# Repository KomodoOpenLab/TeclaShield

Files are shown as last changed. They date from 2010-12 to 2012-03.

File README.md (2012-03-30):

Tecla Shield
============

The [Tecla Shield](http://mobile-accessibility.idrc.ocad.ca/projects/tekla/the-shield) is a device that enables connection of powered wheelchairs and adapted switches to Bluetooth-enabled electronic devices. Together with the [Tecla App](http://komodoopenlab.com/tecla/the-app/), the Tecla Shield may be used to access and control Android-powered devices and is also available for the iPhone and iPad.

Getting Involved
----------------
There are many ways to contribute to the development of the Tecla Shield. Here are some ideas:

### Code

In order to start contributing code and/or designs to the Tecla Shield project, follow the steps below:

1. Fork this repo. For detailed instructions visit [http://help.github.com/fork-a-repo/](http://help.github.com/fork-a-repo/)
2. To work on the firmware, download and install the [Arduino software](http://arduino.cc/en/Main/Software)
3. The firmware for the Tecla Shield is available in the *sketches* directory, simply open the project you want to work on from the Arduino development environment.
4. Hack away! but please make sure you follow [this branching model] (http://nvie.com/posts/a-successful-git-branching-model/). That means, make your pull requests against the **develop** branch, not the **master** branch.

### Review

Another very useful way to contribute to the Tecla Shield project is to identify any bugs or issues that may still be lurking around. You can also submit requests for the features that you think the Tecla Shield is still missing. To get started, follow the steps below:

1. [Sign up for a fee github account](https://github.com/signup/free) if you don't already have one
2. Report issues and submit feature requests to your heart's content via a the [Tecla Shield issues page](https://github.com/jorgesilva/TeclaShield/issues)

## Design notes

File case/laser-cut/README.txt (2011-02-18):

Case adapted from: Laser cut Ethernet shield / Arduino enclosure
URL: http://www.thingiverse.com/thing:5044
Original author: teabot (http://www.thingiverse.com/teabot)
Modified for Tekla on February 13, 2011 by Jorge Silva
Copyright (c) 2011, Inclusive Design Research Centre

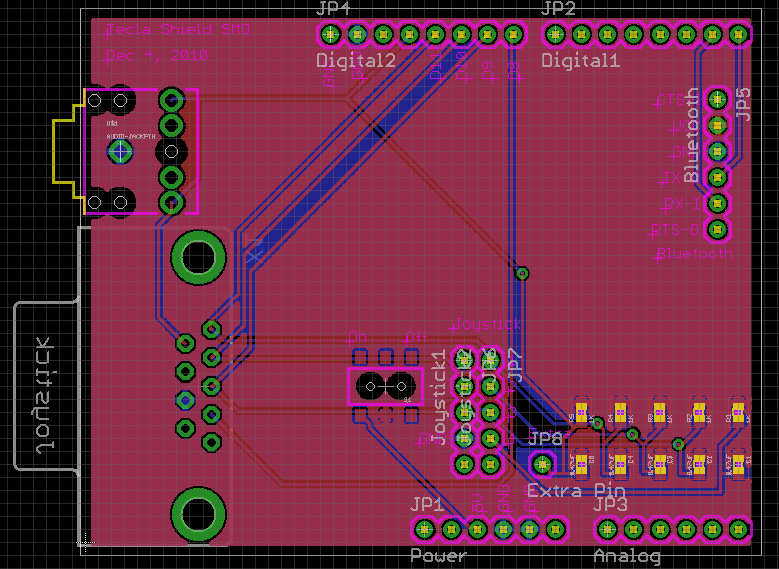
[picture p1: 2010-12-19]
board/SMD/TeklaShieldSMD.PNG

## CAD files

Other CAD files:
case/3d-model/case-bottom.skp
case/3d-model/case-everything.skp
case/3d-model/case-top.skp

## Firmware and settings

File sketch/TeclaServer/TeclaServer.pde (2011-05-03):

/*
 created  27 Sep 2005
 modified 30 Dec 2009 by Tom Igoe
 	
 modified for Tekla
 25 May 2010 by Jorge Silva,
 3 June 2010 by Zongyi Yang
 3 May 2011 by Jorge Silva
 
 */

// Variables will change:
byte switchState = 0x3F;       // current switch states
byte extraState = 0x0C;        // extra switch state helper
byte prevSwitchState = 0x3F;   // previous switch states
byte mByte;                    // used to store incoming serial port data

void setup() {
  // initialize inputs without changing the direction of pins we don't care about
  // 0 = input, 1 = output
  DDRC &= 0xF0; // Joystick inputs
  DDRD &= 0xF3; // Extra inputs
  // initialize serial communication
  Serial.begin(115200);
}


void loop() {
  // if incoming byte
  if (Serial.available() > 0) {
    // get incoming byte:
    mByte = Serial.read();
    // echo incoming byte:
    Serial.write(mByte);
  } else {
    // read the switch states (6 switches):
    switchState = PINC & 0x0F;  // read joystick switches
    extraState = PIND & 0x0C;   // read extra switches
    extraState <<= 2;           // shift extra switches to most significant nibble
    switchState |= extraState;  // copy extra switches to switchState
    // compare the switchState to its previous state
    if (switchState != prevSwitchState) {
      // if the state has changed, send to serial port
      Serial.write(switchState);
      // save the current state as the last state for next time through the loop
      prevSwitchState = switchState;
    }
  }
}

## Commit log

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2010-05-25 Adding latest arduino code for server. Implements full bluetooth edge detection notification functionality.
2010-05-25 Had to create full_server folder and move the code into it for the arduino IDE to read it properly
2010-05-31 Added python testing server with no SDP/UUID support so Android client must connect via:
    Method m = dev.getClass().getMethod("createRfcommSocket", new Class[] { int.class });
    sock = (BluetoothSocket)m.invoke(dev, Integer.valueOf(1));
    instead of using a UUID through SDP as it is the case with the BlueSMiRF module.
2010-06-04 Moved sensors block to feed input method in architecture diagram for android client
2010-06-04 Added schemtatic, still unfinished. Only need to connect serial port to circuit
    [untitled.sch]
2010-06-05 Turned bluetooth connection code into a service providing switch event broadcasts to the OS.
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2010-06-28 Tried again. Apparently adding the folder doesn't add the contents inside
    [schematic.brd, schematic.sch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]
2010-07-12 Added V3 and V4 of sheild. They are through hole and smd respectively, and include the audio jack.
    [schematic.brd, schematic.sch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]
2010-08-06 + Input method is now forced open after first use. + Lots of refactoring in preparation for merge with switch event provider and packaging/release!
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2010-08-16 Cleaned up files
    [Tecla Shield Through Hole V1.brd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]
2010-08-18 + Added full android client project based on switch event provider + Service starts at boot
2010-08-18 + Merged input method code + Eliminated boot startup code for switch event provider + Fixes #620054
2010-08-18 Merged separate switch event intents into a single one by using the Extras bundle
2010-08-19 + Started refactoring to break up long methods. Lots of work needed. + IME is now responding to bluetooth events from external switches
2010-08-20 + Added helper placeholder class to break up IME code + Renamed SwitchEventProvider and InputMethod files + Added direct toch support + Found and fixed a few crashing bugs from refactoring + Function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
2010-08-23 Renamed Files and cleaned them up
    [Tecla Shield SMD.brd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]
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2010-08-30 Updated designs folder structure
    [Tecla Shield SMD.brd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]
2010-08-30 Renamed shield files from tecla to tekla and eliminated spaces in file names
    [TeklaShieldSMD.brd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]
2010-09-07 Included case designs in a google sketchup file under designs/case
    [case_everything.skp]
2010-09-07 Fixed small bug in the design
    [case_everything.skp]
2010-09-07 Separated the case into the top and bottom piece in separate files.
    [case_bottom.skp, case_top.skp]
2010-09-07 Deleted some extra lines in the bottom piece
    [case_bottom.skp, case_everything.skp]
2010-09-20 Last case did not fit arduino, made following changes:
    Made all holes wider
    One pin out of the 3 on the ardiuno was a little out of place, moved it to correct place
    Widened case
    Changed some sizes such that there is a 0.5mm gap between pieces that fit together.
    [case_bottom.skp, case_everything.skp, case_top.skp]
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2010-10-04 Modified sheild files to extend the inputs a bit further.
    Also cleaned up some files
    [TeklaShieldSMD.brd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]
2010-10-04 forgot to update the date, now fixed
    [TeklaShieldSMD.brd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]
2010-10-08 Minor changes to shield component names
    [TeklaShieldSMD.brd, TeklaShieldSMD.sch, TeklaShieldThroughHole.brd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]
2010-10-08 Removed shield CAM files
    [TeklaShieldSMD.GBL, TeklaShieldSMD.GBS, TeklaShieldSMD.GTL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]
2010-10-11 + Initial commit for Android 0.2-alpha + Removed all Android 0.1.X alpha code + Added builtin LatinIME with changed references to public APIs + Still need to recreate a couple internal resources that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
2010-10-16 + Connected switch event provider (Android) + Start at boot with last saved shield (Android) + Some refactoring + Still missing highlighting + Still missing connection to input method
2010-10-29 + Connected switch event provider with input method + Highlighting still needs to be solved
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2010-11-08 + Refactored some functions + Created a helper class to share code amongst other classes + Fixing reconnect logic of switch event provider to account for various use cases
2010-11-10 Reverting sip&puff filter on shield (must implement on clients)
2010-11-19 Added code to handle 5th switch on Tekla Shield. Had to flip it for compatibility with previous versions.
2010-11-30 Fixed labels on TH board
    [TeklaShieldThroughHole.brd]
2010-12-04 flipped bluetooth board, new boards plug in with lights facing up. moved bluetooth board 2mm inwards away from edge retracted everything on port side 2.1mm added a connection wire between pin 6 on d9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
    MAKE SURE BLUETOOTH BOARDS PLUG IN THE RIGHT WAY
    [TeklaShieldSMD.brd, TeklaShieldSMD.sch, TeklaShieldThroughHole.brd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]
2010-12-19 Updated Tekla Shield silk screen labels
    [TeklaShieldSMD.brd, TeklaShieldThroughHole.brd]
2011-01-26 Changed through hole board so that the board layout matches that of the Arduino uno board.
    [TeklaShieldThroughHole.brd]
2011-01-26 It seems like the last commit corrupted the through hole board file, I will commit again
    [TeklaShieldThroughHole.brd]
2011-02-02 Fixed some minor DRC issues
    [TeklaShieldThroughHole.brd, TeklaShieldThroughHole.sch]
2011-02-02 Isolated joystick and extra switches common
    [TeklaShieldThroughHole.brd, TeklaShieldThroughHole.sch]
2011-02-06 Removed redundancy between extra and DE9 switches in shield
    [TeklaShieldThroughHole.brd, TeklaShieldThroughHole.sch]
2011-02-08 DRC fixes on the Tekla Shield board
    [TeklaShieldThroughHole.brd]
2011-02-08 Fixed ground net naming
    [TeklaShieldThroughHole.brd, TeklaShieldThroughHole.sch]
2011-02-08 Fixed placement of stereo plug in Tekla Shield
    [TeklaShieldThroughHole.brd]
2011-02-09 Making branch exclusive to Tekla Shield
    [TeklaShieldSMD.brd, TeklaShieldSMD.sch, TeklaShieldThroughHole.brd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]
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2011-02-14 Fixed positioning of DE9 connector and changed some labels Should be ready for release
    [TeklaShieldThroughHole.brd]
2011-02-14 Added laser-cut case drawing Renamed 3D case designs
    [case-laser.dxf, case_3D_bottom.skp, case_3D_everything.skp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]
2011-02-15 Updated joystick header labels
    [TeklaShieldThroughHole.brd]
2011-02-15 Minor label edits and trace changes
    [TeklaShieldThroughHole.brd]
2011-02-15 Updated date on board
    [TeklaShieldThroughHole.brd]
2011-02-15 Updated component values
    [TeklaShieldThroughHole.brd, TeklaShieldThroughHole.sch]
2011-02-16 Separated laser-cut case into interior and exterior layers
    [case-laser.dxf]
2011-02-17 Connected CTS and RTS on bluesmirf module
    [TeklaShieldThroughHole.brd, TeklaShieldThroughHole.sch]
2011-02-18 Fixed an issue with the Proto II (unrouted VCC) Updated sketch
    [TeklaShieldThroughHole.brd]
2011-02-18 Re-arranged case files and added laser-cut attribution and copyright info
    [case-bottom.skp, case-everything.skp, case-top.skp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]
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2011-02-21 Moved Extra 2 switch to Arduino PORTD2 to avoid load on PORTB5
    [TeklaShieldThroughHole.brd, TeklaShieldThroughHole.sch]
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2011-03-03 Changed switch locations for future compatibility with Goldeneye Project
    [TeklaShieldThroughHole.brd, TeklaShieldThroughHole.sch]
2011-03-04 Minor adjustments to laser-cut case
    [case.dxf]
2011-03-04 Increased size of 3.5mm plug cutout to account for standard plug housings
    [case.dxf]
2011-03-04 Rounded laser-cut case corners on DE9 cutout and increased size of 3.5mm cutout
    [case.dxf]
2011-03-05 Minor edits to 3.5mm, DE9 and power cutouts in laser-cut Tekla case
    [case.dxf]
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2011-08-10 Fixed ground and Vcc plane isolate value (to 12mils)
    [TeklaShieldThroughHole.brd]
2011-08-10 Updated shield modification date
    [TeklaShieldThroughHole.brd]
2012-01-20 Eliminating deprecated files from repository
    [untitled.sch]
